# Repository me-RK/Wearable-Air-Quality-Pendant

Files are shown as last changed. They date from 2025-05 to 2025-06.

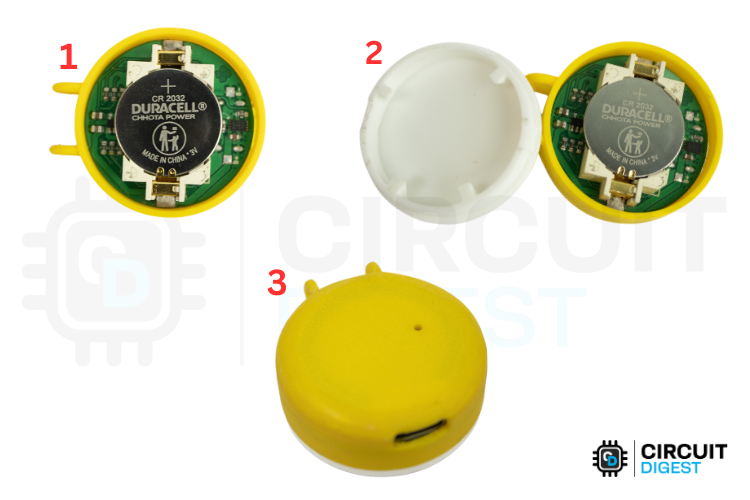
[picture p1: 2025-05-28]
Images/Assembled PCB and Enclosure.png

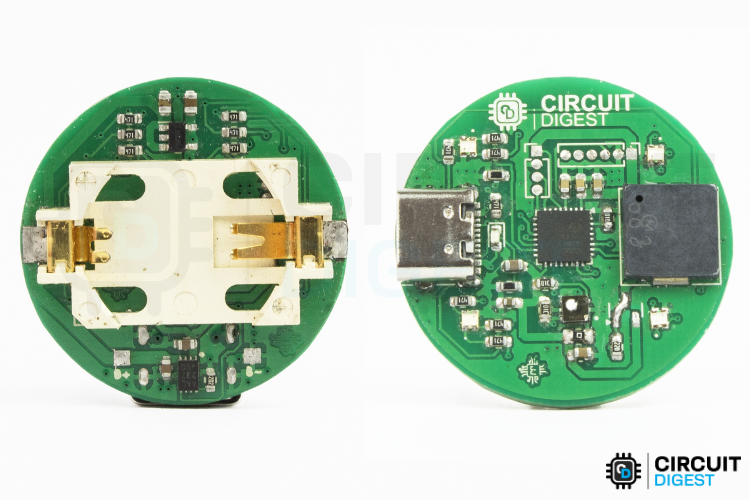
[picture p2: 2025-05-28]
Images/Assembled PCB front and Back.png

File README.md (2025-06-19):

Wearable Air Quality Pendant 🌬️
================================

A compact, battery-powered wearable device that continuously monitors air quality using TVOC detection. Get real-time feedback about your breathing environment through intuitive LED indicators and audio alerts.

Wearable Air Quality Pendant

Project Overview
-------------------

This DIY air quality monitor pendant uses professional-grade sensors to track Total Volatile Organic Compounds (TVOC) in real-time. Perfect for monitoring indoor air quality at home, office, or industrial environments.

### Key Features

-    **Real-time TVOC monitoring** using SGP40 sensor
-    **Ultra-low power design** with STM32U083KCU6 microcontroller
-    **Intuitive feedback** - Color-coded LEDs and musical alerts
-    **Wearable design** - Compact 32.5mm diameter pendant
-    **All-day battery life** with efficient power management
-    **Professional accuracy** with industrial-grade sensor

 Air Quality Classifications
------------------------------

| TVOC Level | Status | LED Color | Audio Alert |
| --- | --- | --- | --- |
| 0-200 | Good | 🟢 Green | Soft tone |
| 201-300 | Warning | 🟡 Yellow | Warning melody |
| 301-500 | Alarm | 🔴 Red | Urgent beeping |
| >500 | Error | 🔴 Flashing Red | Error tone |

 Hardware Components
-----------------------

### Main Components

-   **STM32U083KCU6** - Ultra-low-power microcontroller
-   **SGP40-D-R4** - Professional TVOC air quality sensor
-   **MCP73832T** - Li-Po battery charge controller
-   **ADPL44002** - Low-dropout voltage regulator
-   **EAST1616RGBA1** - RGB LEDs (4x)
-   **PKMCS0909E4000-R1** - Piezoelectric buzzer

### Power Management

-   Li-Po battery charging via USB-C
-   Regulated 2.5V supply for stable operation
-   Ultra-low power consumption for all-day use

📁 Repository Structure
-----------------------

```
├── Code/
│   └── Wearable_Air_Quality_Pendant/
│       ├── Wearable_Air_Quality_Pendant.ino
│       └── libraries/
├── PCB/
│   ├── Wearable-Air-Quality-Pendant.kicad_pro
│   ├── Schematic.pdf
│   └── Gerber_Files/
├── 3D_Models/
│   ├── Pendant_Top.stl
│   ├── Pendant_Bottom.stl
│   └── Assembly_Guide.pdf
├── Documentation/
│   ├── Circuit_Diagram.pdf
│   ├── Assembly_Instructions.pdf
│   └── BOM.csv
└── images/

```

🚀 Quick Start Guide
--------------------

### 1\. Hardware Assembly

1.  **Order PCB**: Use provided Gerber files
2.  **Solder components**: Follow the detailed BOM
3.  **3D print enclosure**: Use provided STL files
4.  **Assemble**: Insert PCB into printed enclosure

### 2\. Software Setup

1.  **Install Arduino IDE** (version 1.8.19 or newer)
2.  **Add STM32 board support**
3.  **Install required libraries**:
    -   DFRobot_SGP40
    -   PlayRtttl
    -   ptScheduler
4.  **Upload firmware** using ST-Link programmer

 Required Libraries
---------------------

Add these libraries through Arduino IDE Library Manager:

```
#include <DFRobot_SGP40.h>     // SGP40 sensor communication
#include <PlayRtttl.hpp>       // Musical tone generation
#include <ptScheduler.h>       // Non-blocking task scheduling

```

 Programming the Device
------------------------

### Hardware Requirements

-   **ST-Link V2 programmer** (required for STM32)
-   **USB-C cable** for power and charging
-   **3.3V power supply** during programming

### Upload Process

1.  Connect ST-Link to SWD pins (SWDIO, SWCLK)
2.  Select board: "STM32U0 series" in Arduino IDE
3.  Select programmer: "STM32CubeProgrammer (SWD)"
4.  Upload firmware

 PCB Specifications
---------------------

-   **Dimensions**: 32.5mm diameter
-   **Layers**: 2-layer PCB
-   **Thickness**: 1.6mm
-   **Components**: SMD (0603/0402 packages)
-   **Connector**: USB-C for charging

 3D Printing Guide
---------------------

### Print Settings

-   **Layer Height**: 0.2mm
-   **Infill**: 20%
-   **Supports**: Minimal (only for overhangs)
-   **Material**: PLA or PETG recommended

### Post-Processing

-   Light sanding for smooth finish
-   Ensure USB-C port alignment
-   Test fit before final assembly

Acknowledgments
------------------

-   **CircuitDigest** - Project development and documentation
-   **DFRobot** - SGP40 sensor library
-   **STMicroelectronics** - STM32 microcontroller support
-   **DigiKey** - Sponsors

Support
----------

-   **Detailed Tutorial**: [CircuitDigest Article](https://circuitdigest.com/videos/wearable-air-quality-pendant)
-   **Video Guide**: [YouTube Tutorial](https://youtube.com/watch?v=c5lP1kzYoBA)
-   **Issues**: Report bugs via GitHub Issues
-   **Discussion**: Join our community forum

Version History
-------------------

| Version | Date | Changes |
| --- | --- | --- |
| v1.0 | 2024-12 | Initial release |
| v1.1 | 2025-01 | Bug fixes, improved battery life |

* * * * *

**⭐ If this project helped you, please star the repository!**

**🔗 Related Projects:**

-   [Arduino Air Quality Monitor](https://github.com/Circuit-Digest/Arduino-Air-Quality-Monitor)
-   [IoT Air Quality System](https://github.com/Circuit-Digest/IoT-Air-Quality-System)

**📧 Contact:** support@circuitdigest.com

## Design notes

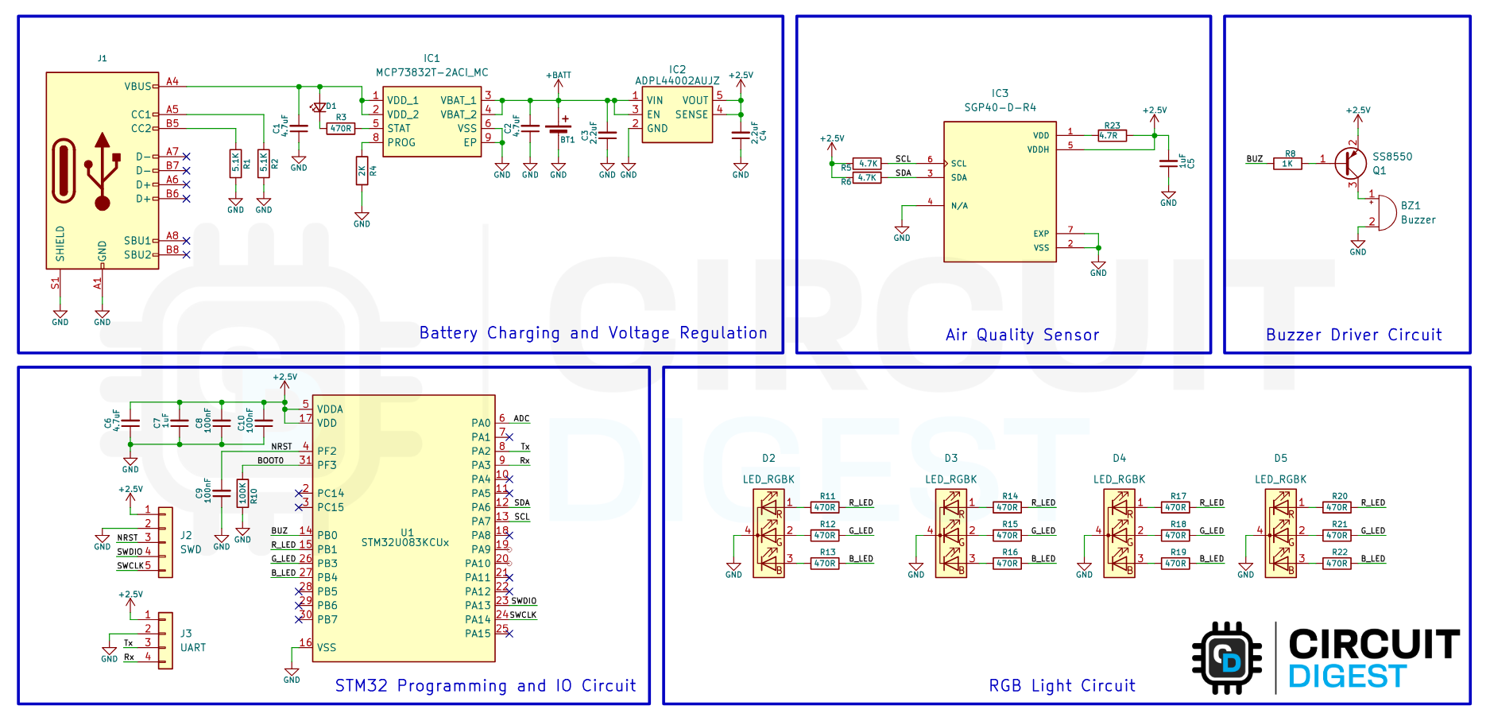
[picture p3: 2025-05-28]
Images/Schematic.png

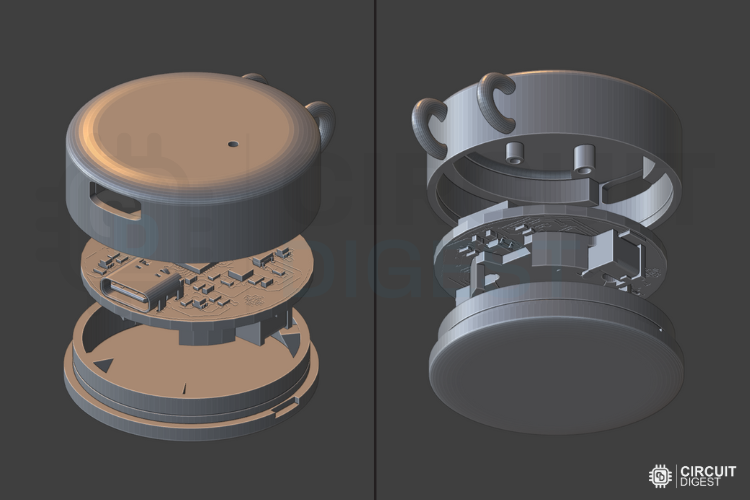
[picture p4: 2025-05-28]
Images/3D Enclosure DEsign.png

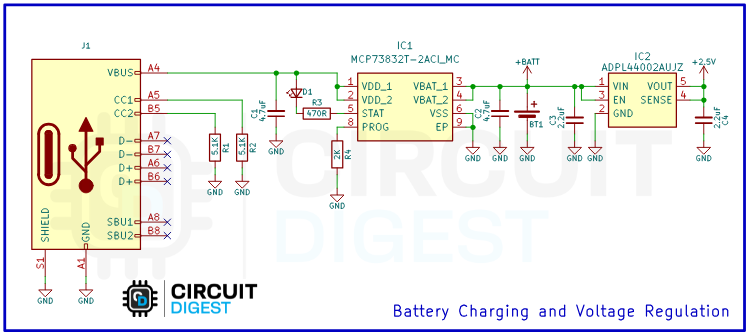
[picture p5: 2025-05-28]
Images/Battery Charging and Voltage Regulation.png

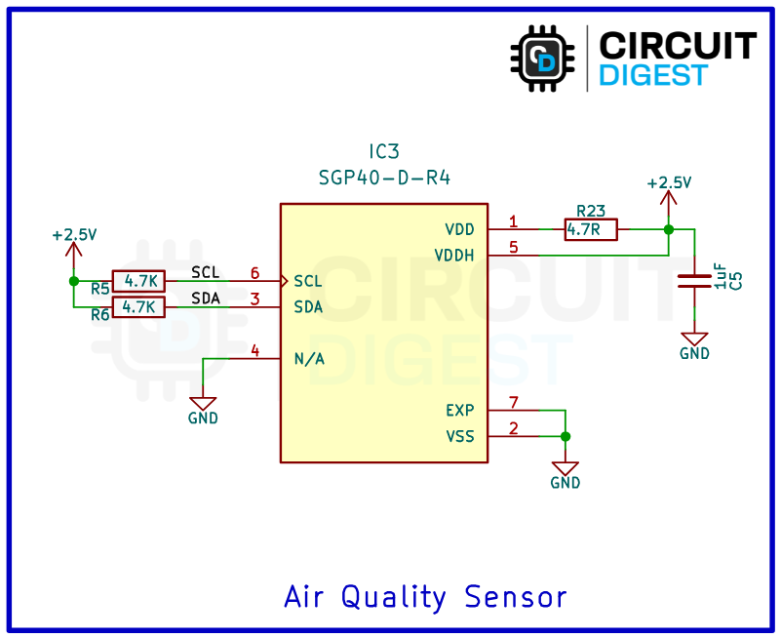
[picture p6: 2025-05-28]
Images/Air Quality Sensor.png

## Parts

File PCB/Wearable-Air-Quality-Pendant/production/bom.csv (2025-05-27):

Designator | Footprint | Quantity | Value | LCSC Part #
_2, |  | 2
BT1 | BAT_1060 | 1 | Battery_Cell
BZ1 | PKMCS0909E4000-R1_MUR | 1 | Buzzer
C1, C2, C6 | 0603 | 3 | 4.7uF
C10, C8, C9 | 0603 | 3 | 100nF
C3, C4 | 0603 | 2 | 2.2uF
C5, C7 | 0603 | 2 | 1uF
D1 | 0603 | 1 | LED_Small
D2, D3, D4, D5 | EAST1616RGBA1 | 4 | LED_RGBK
IC1 | SON50P300X200X100-9N-D | 1 | MCP73832T-2ACI_MC
IC2 | SOT95P280X100-5N | 1 | ADPL44002AUJZ
IC3 | XCDR_SGP40-D-R4 | 1 | SGP40-D-R4
J1 | USB_C_Receptacle_Palconn_UTC16-G | 1 | USB_C_Receptacle_USB2.0_16P
J2 | PinHeader_1x06_P1.27mm_Vertical | 1 | SWD
J3 | PinHeader_1x04_P1.27mm_Vertical | 1 | UART
Q1 | SOT-23 | 1 | SS8550
R1, R2 | 0603 | 2 | 5.1K
R10 | 0603 | 1 | 100K
R11, R12, R13, R14, R15, R16, R17, R18, R19, R20, R21, R22, R3 | 0603 | 13 | 470R
R23 | 0805 | 1 | 4.7R
R4 | 0603 | 1 | 2K
R5, R6 | 0603 | 2 | 4.7K
R8 | 0603 | 1 | 1K
U1 | QFN-32-1EP_5x5mm_P0.5mm_EP3.45x3.45mm | 1 | STM32U083KCUx

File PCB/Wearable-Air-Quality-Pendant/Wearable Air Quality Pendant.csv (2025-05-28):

Reference | Qty | Value | Datasheet | Manufacturer_Name | Manufacturer_Part_Number
BT1 | 1 | Battery_Cell | ~
BZ1 | 1 | Buzzer | ~
C1,C2,C6 | 3 | 4.7uF | ~
C3,C4 | 2 | 2.2uF | ~
C5,C7 | 2 | 1uF | ~
C8,C9,C10 | 3 | 100nF | ~
D1 | 1 | LED_Small | ~
D2,D3,D4,D5 | 4 | LED_RGBK | ~
IC1 | 1 | MCP73832T-2ACI_MC | http://ww1.microchip.com/downloads/en/DeviceDoc/20001984g.pdf | Microchip | MCP73832T-2ACI/MC
IC2 | 1 | ADPL44002AUJZ | https://www.analog.com/ADPL44002/datasheet | Analog Devices | ADPL44002AUJZ2.5-R7
IC3 | 1 | SGP40-D-R4
J1 | 1 | USB_C_Receptacle_USB2.0_16P | https://www.usb.org/sites/default/files/documents/usb_type-c.zip
J2 | 1 | SWD | ~
J3 | 1 | UART | ~
Q1 | 1 | SS8550 | http://www.secosgmbh.com/datasheet/products/SSMPTransistor/SOT-23/SS8550.pdf
R1,R2 | 2 | 5.1K | ~
R3,R11,R12,R13,R14,R15,R16,R17,R18,R19,R20,R21,R22 | 13 | 470R | ~
R4 | 1 | 2K | ~
R5,R6 | 2 | 4.7K | ~
R8 | 1 | 1K | ~
R10 | 1 | 100K | ~
R23 | 1 | 4.7R | ~
U1 | 1 | STM32U083KCUx | https://www.st.com/resource/en/datasheet/stm32u083kc.pdf

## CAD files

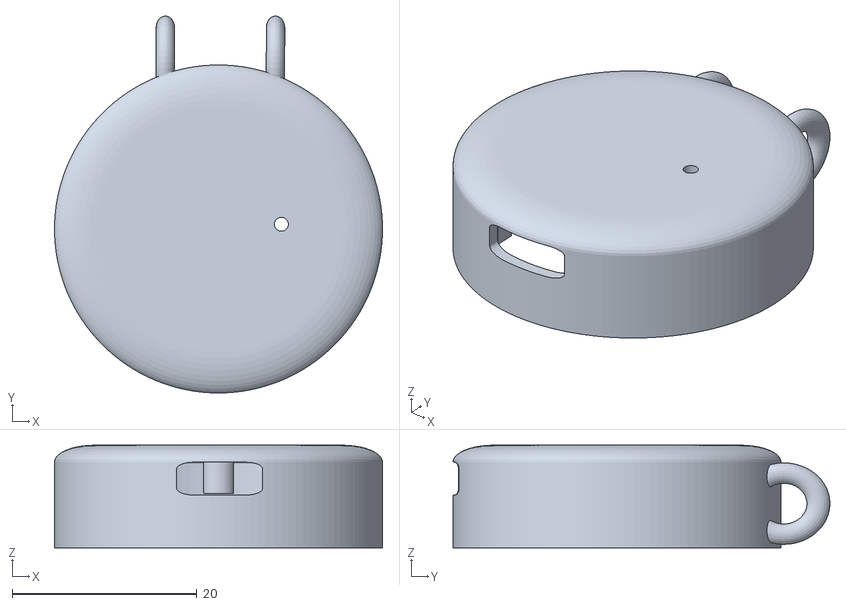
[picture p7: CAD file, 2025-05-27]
Enclosure STL Files/Wearable_Air_Quality_Pendant_Top.stl
35.5 x 40.8 x 11.1

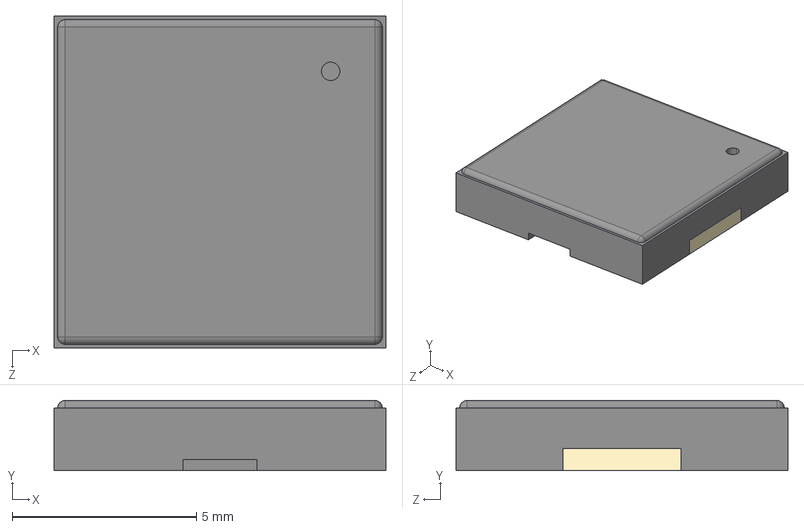
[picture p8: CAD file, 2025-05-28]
PCB/Wearable-Air-Quality-Pendant/3d Models/PKMCS0909E4000-R1.STEP
9.00 x 1.90 x 9.00 mm

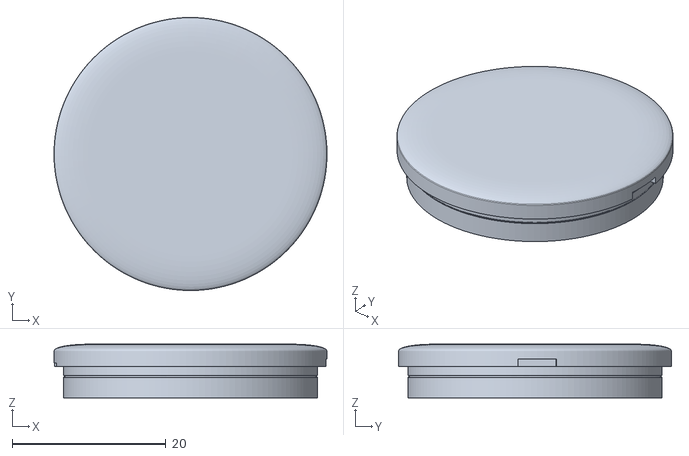
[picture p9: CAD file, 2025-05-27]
Enclosure STL Files/Wearable_Air_Quality_Pendant_Bottom.stl
35.5 x 35.5 x 6.97

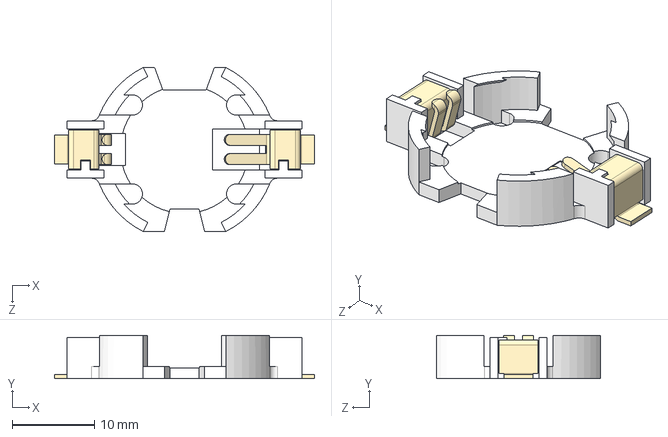
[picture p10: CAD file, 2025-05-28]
PCB/Wearable-Air-Quality-Pendant/3d Models/BU2032SM-JJ-GTR.STEP
31.7 x 5.30 x 20.0 mm

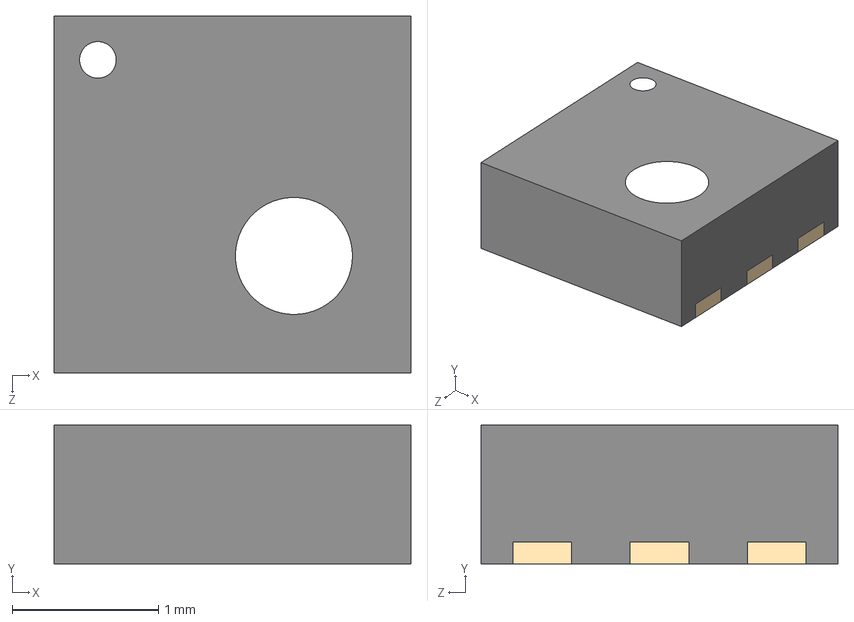
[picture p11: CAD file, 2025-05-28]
PCB/Wearable-Air-Quality-Pendant/3d Models/SGP40-D-R4.STEP
2.44 x 0.95 x 2.44 mm

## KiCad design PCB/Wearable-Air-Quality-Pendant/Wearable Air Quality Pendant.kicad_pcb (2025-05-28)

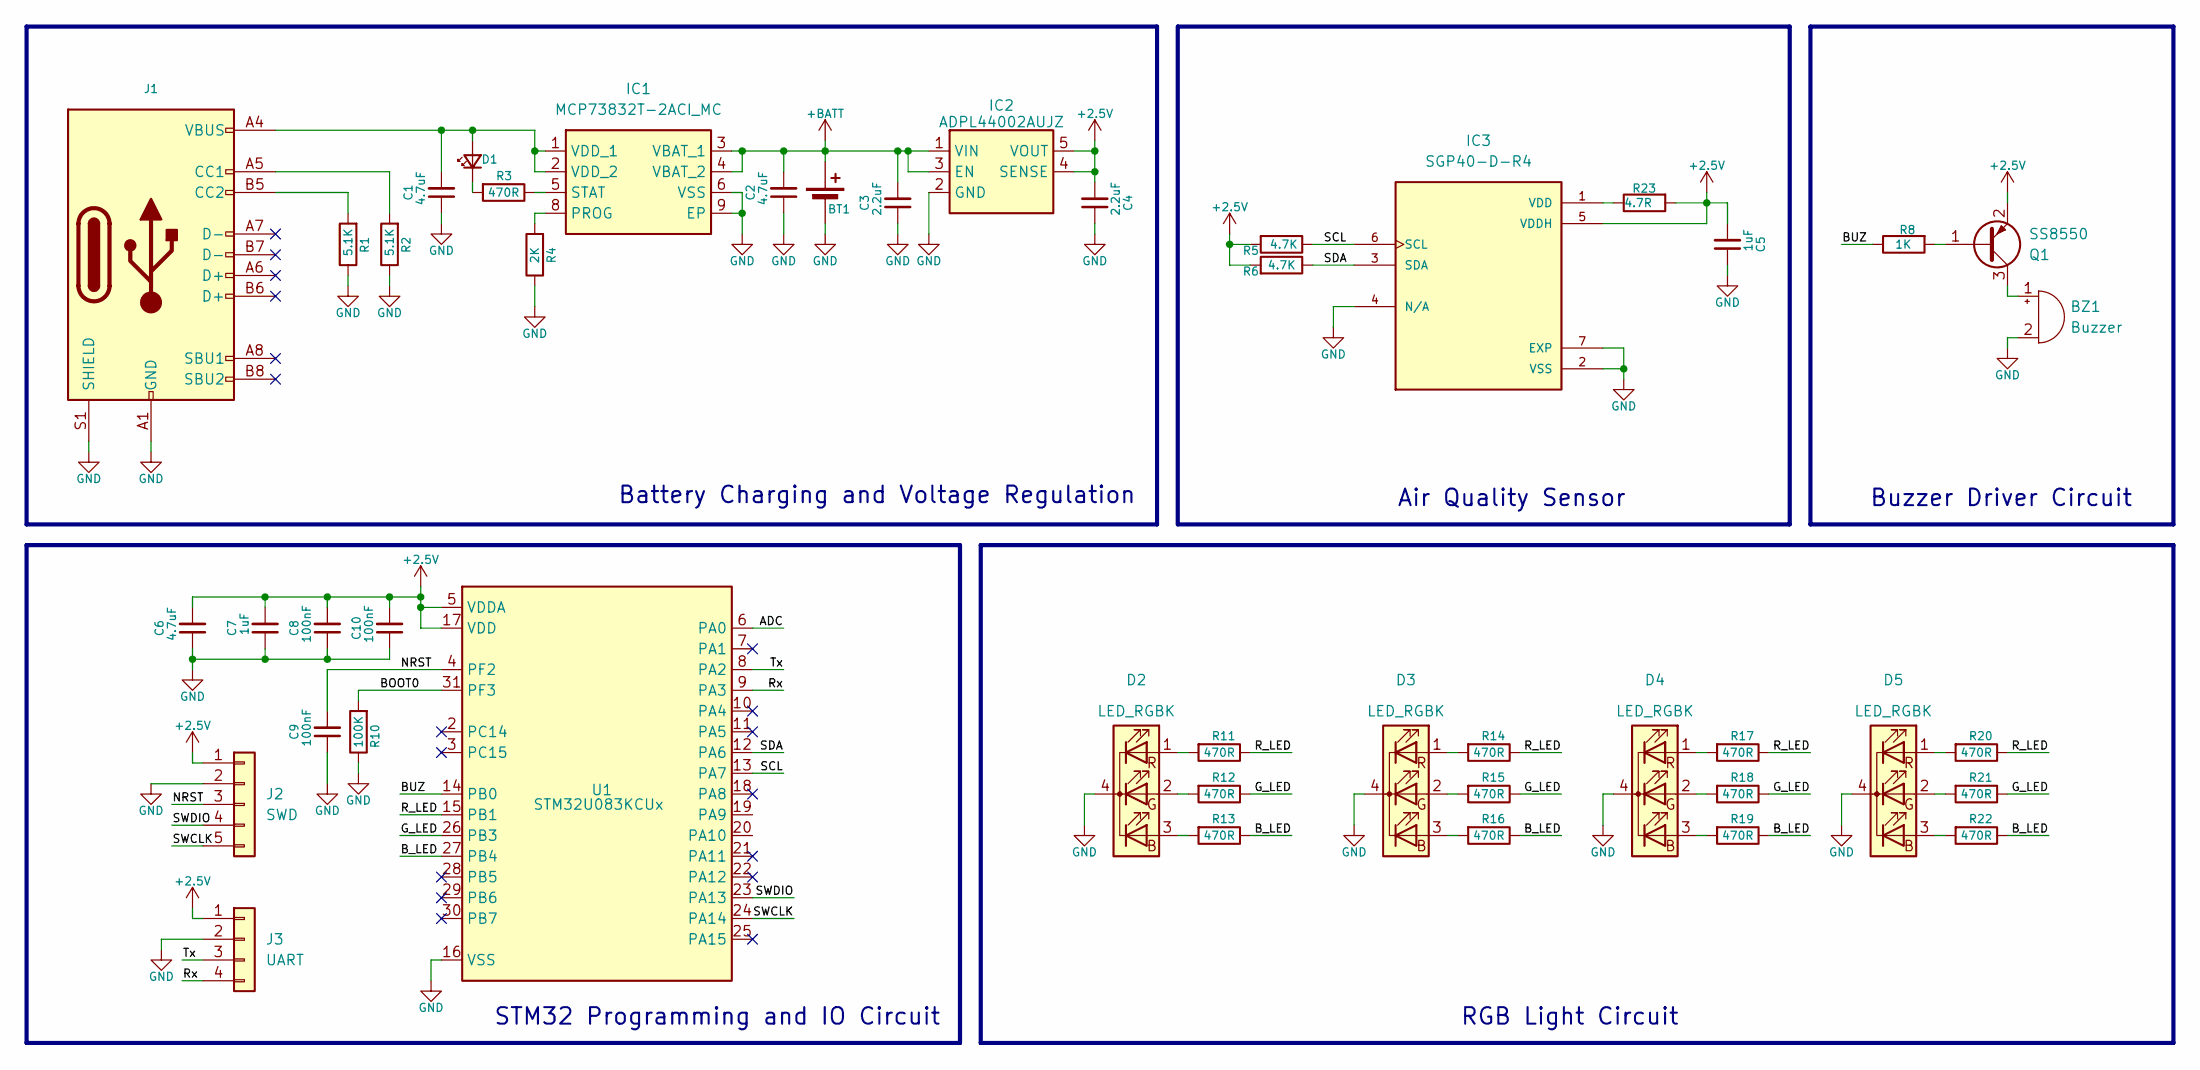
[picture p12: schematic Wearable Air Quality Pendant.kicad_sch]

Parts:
BT1: Battery_Cell; BAT_1060
BZ1: Buzzer; PKMCS0909E4000-R1_MUR
C1, C2, C6: 4.7uF; C_0603_1608Metric
C3, C4: 2.2uF; C_0603_1608Metric
C5, C7: 1uF; C_0603_1608Metric
C8, C9, C10: 100nF; C_0603_1608Metric
D1: LED_Small; LED_0603_1608Metric
D2, D3, D4, D5: LED_RGBK; EAST1616RGBA1
IC1: MCP73832T-2ACI_MC; SON50P300X200X100-9N-D; Mouser Part Number 579-MCP73832T-2ACIMC
IC2: ADPL44002AUJZ; SOT95P280X100-5N; Manufacturer_Part_Number ADPL44002AUJZ2.5-R7
IC3: SGP40-D-R4; XCDR_SGP40-D-R4; PARTREV 1.2
J1: USB_C_Receptacle_USB2.0_16P; USB_C_Receptacle_Palconn_UTC16-G
J2: SWD; PinHeader_1x06_P1.27mm_Vertical
J3: UART; PinHeader_1x04_P1.27mm_Vertical
Q1: SS8550; SOT-23
R1, R2: 5.1K; R_0603_1608Metric
R3, R11, R12, R13, R14, R15, R16, R17, R18, R19, R20, R21, R22: 470R; R_0603_1608Metric
R4: 2K; R_0603_1608Metric
R5, R6: 4.7K; R_0603_1608Metric
R8: 1K; R_0603_1608Metric
R10: 100K; R_0603_1608Metric
R23: 4.7R; R_0805_2012Metric
U1: STM32U083KCUx; QFN-32-1EP_5x5mm_P0.5mm_EP3.45x3.45mm

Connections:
+2.5V: C4.2, C5.2, C6.2, C7.2, C8.2, C10.2, IC2.4 (SENSE), IC2.5 (VOUT), IC3.5 (VDDH), J2.1, J3.1, Q1.2 (E), R5.2, R6.2, R23.2, U1.1 (VDD), U1.5 (VDDA), U1.17 (VDD)
+BATT: BT1.P (+), C2.2, C3.2, IC1.3 (VBAT_1), IC1.4 (VBAT_2), IC2.1 (VIN), IC2.3 (EN)
/ADC: U1.6 (PA0)
/BOOT0: R10.2, U1.31 (PF3)
/BUZ: R8.1, U1.14 (PB0)
/B_LED: R13.1, R16.1, R19.1, R22.1, U1.27 (PB4)
/G_LED: R12.1, R15.1, R18.1, R21.1, U1.26 (PB3)
/NRST: C9.2, J2.3, U1.4 (PF2)
/R_LED: R11.1, R14.1, R17.1, R20.1, U1.15 (PB1)
/Rx: J3.4, U1.9 (PA3)
/SCL: IC3.6 (SCL), R5.1, U1.13 (PA7)
/SDA: IC3.3 (SDA), R6.1, U1.12 (PA6)
/SWCLK: J2.5, U1.24 (PA14)
/SWDIO: J2.4, U1.23 (PA13)
/Tx: J3.3, U1.8 (PA2)
GND: BT1.N (-), BZ1.2 (-), C1.1, C2.1, C3.1, C4.1, C5.1, C6.1, C7.1, C8.1, C9.1, C10.1, D2.4 (K), D3.4 (K), D4.4 (K), D5.4 (K), IC1.6 (VSS), IC1.9 (EP), IC2.2 (GND), IC3.2 (VSS), IC3.4 (N/A), IC3.7 (EXP), J1.A1 (GND), J1.A12 (GND), J1.B1 (GND), J1.B12 (GND), J1.S1 (SHIELD), J2.2, J3.2, R1.1, R2.1, R4.1, R10.1, U1.16 (VSS), U1.32 (VSS), U1.33 (VSS)
unnamed: BZ1.1 (+), Q1.3 (C)
unnamed: C1.2, D1.2 (A), IC1.1 (VDD_1), IC1.2 (VDD_2), J1.A4 (VBUS), J1.A9 (VBUS), J1.B4 (VBUS), J1.B9 (VBUS)
unnamed: D1.1 (K), R3.2
unnamed: D2.3 (BA), R13.2
unnamed: D2.2 (GA), R12.2
unnamed: D2.1 (RA), R11.2
unnamed: D3.3 (BA), R16.2
unnamed: D3.2 (GA), R15.2
unnamed: D3.1 (RA), R14.2
unnamed: D4.3 (BA), R19.2
unnamed: D4.2 (GA), R18.2
unnamed: D4.1 (RA), R17.2
unnamed: D5.3 (BA), R22.2
unnamed: D5.2 (GA), R21.2
unnamed: D5.1 (RA), R20.2
unnamed: IC1.8 (PROG), R4.2
unnamed: IC1.5 (STAT), R3.1
unnamed: IC3.1 (VDD), R23.1
unnamed: J1.A5 (CC1), R2.2
unnamed: J1.B5 (CC2), R1.2
unnamed: Q1.1 (B), R8.2

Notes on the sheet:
Air Quality Sensor
STM32 Programming and IO Circuit
Battery Charging and Voltage Regulation
RGB Light Circuit
Buzzer Driver Circuit

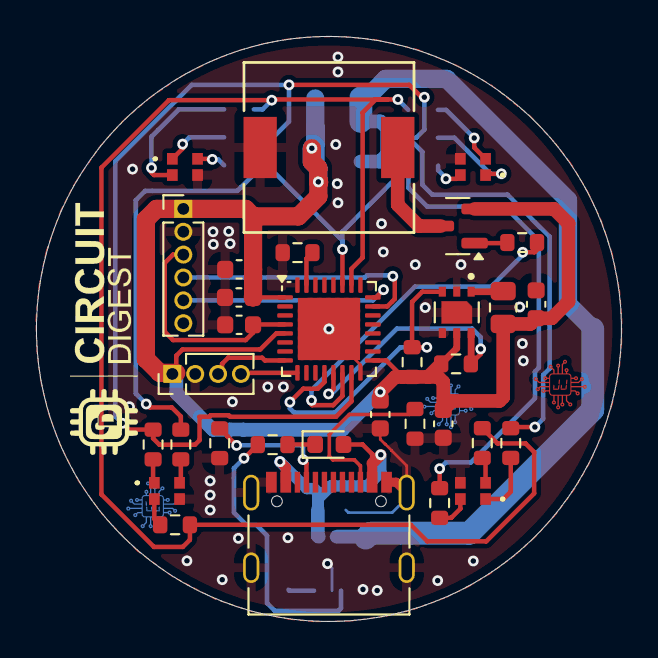
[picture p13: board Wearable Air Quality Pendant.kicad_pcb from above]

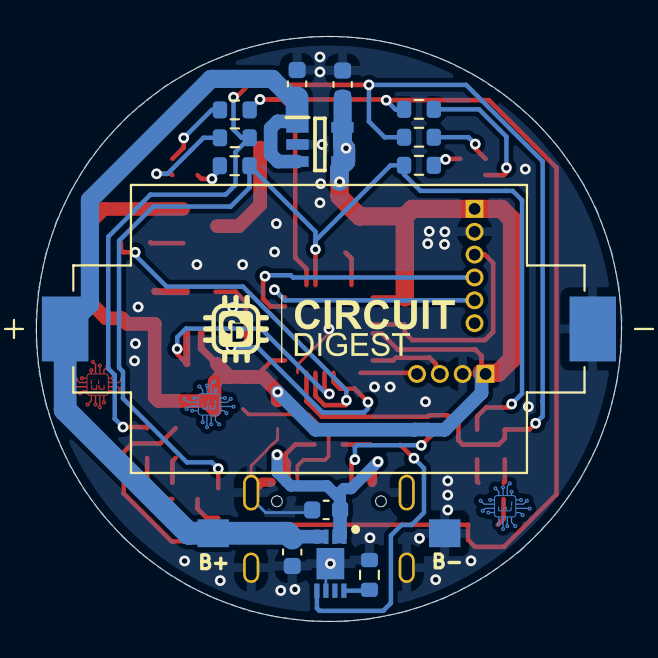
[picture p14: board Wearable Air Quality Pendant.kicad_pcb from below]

Board: 2 copper layers, 32.5 x 32.5 mm, 46 parts (14 on the bottom side), 36 nets.

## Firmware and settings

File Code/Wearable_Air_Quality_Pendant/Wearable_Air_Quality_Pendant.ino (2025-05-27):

/*
  =======================================================================
  Project: Air Quality Monitor with TVOC Index using SGP40 Sensor

  Features:
  - Reads Total Volatile Organic Compounds (TVOC) index from SGP40 sensor
  - Indicates air quality using LEDs (Red, Green) with smooth fading effect
  - Plays RTTTL tone alerts for different air quality levels via buzzer
  - Displays TVOC values via LPUART serial (PA2, PA3)
  - Shows error states with visual (LED) and audible (buzzer) indication

  Working:
  - SGP40 sensor periodically reads TVOC index
  - Based on the index value, system classifies air as:
      0–200   → Good (Soft tone, Green LED)
      201–300 → Warning (Warn tone, Yellow LED)
      301–500 → Alarm (Alarm tone, Red LED)
  - If TVOC exceeds 500 or sensor fails, Error tone & Red LED flash
  - Scheduler ensures non-blocking periodic sensor read, LED updates, and sound
  =======================================================================
*/

#include <DFRobot_SGP40.h> // need to install
#include <HardwareSerial.h>
#include <Arduino.h>
#include <PlayRtttl.hpp> // need to install
#include <ptScheduler.h> // need to install

// LED and Buzzer pin definitions
#define RED_PIN PB3
#define GREEN_PIN PB4
#define BUZZER_PIN PB0

// Define serial on PA3 (RX) and PA2 (TX)
HardwareSerial MyLPUART1(PA3, PA2);

// Create SGP40 sensor object
DFRobot_SGP40 mySgp40;

// Variables for tone request and fading effect
int tvoc = 0;
int toneRequest = -1;
int fadeStep = 0;

// Time tracking variables for non-blocking operations
unsigned long prevLedTime = 0;
unsigned long prevToneTime = 0;

// Define RTTTL tone melodies
const char softTone[] = "Soft:d=8,o=5,b=100:g";
const char warnTone[] = "Warn:d=4,o=5,b=120:c,e,g";
const char alarmTone[] = "Alarm:d=16,o=5,b=180:c6,c6,c6";
const char startTone[] = "Start:d=8,o=6,b=120:c,e,g";
const char errorTone[] = "Error:d=4,o=5,b=160:c,c,r,c";

// Enum to associate tone types with time intervals
enum ToneType {
  TONE_SOFT = 5000,
  TONE_WARN = 2000,
  TONE_ALARM = 500,
  TONE_START = 1000,
  TONE_ERROR = 200
};

// Task scheduler for non-blocking periodic functions
ptScheduler readSensorTask(PT_TIME_1S);   // Sensor reading every 1 second
ptScheduler lightTask(PT_TIME_100MS);     // LED update task
ptScheduler soundTask(PT_TIME_100MS);     // Buzzer task

// Function declarations
void playTone(ToneType tone);
void updateLedFade(ToneType tone);
void showErrorState();
void readAndEvaluateAir();

void setup() {
  MyLPUART1.begin(115200);

  // Initialize output pins
  pinMode(RED_PIN, OUTPUT);
  pinMode(GREEN_PIN, OUTPUT);
  pinMode(BUZZER_PIN, OUTPUT);

  MyLPUART1.println("sgp40 is starting, the reading can be taken after 10 seconds...");

  // Startup indication
  updateLedFade(TONE_START);
  playTone(TONE_START);

  // Initialize sensor
  if (!mySgp40.begin(10000)) {
    MyLPUART1.println("Failed to init chip. Please check connection.");
    showErrorState();
    while (true);  // Stop execution on failure
  }

  MyLPUART1.println("sgp40 initialized successfully!");
}

void loop() {
  // Periodically read sensor
  if (readSensorTask.call()) {
    readAndEvaluateAir();
  }

  // Update LED fading effect based on tone
  if (lightTask.call() && toneRequest != -1) {
    updateLedFade((ToneType)toneRequest);
  }

  // Play tone based on tone request
  if (soundTask.call() && toneRequest != -1 && toneRequest != TONE_SOFT) {
    playTone((ToneType)toneRequest);
  }
}

// Reads TVOC value and determines air quality level
void readAndEvaluateAir() {
  tvoc = mySgp40.getVoclndex();

  MyLPUART1.print("vocIndex = ");
  MyLPUART1.println(tvoc);

  if (tvoc <= 200) {
    toneRequest = TONE_SOFT;
  } else if (tvoc <= 300) {
    toneRequest = TONE_WARN;
  } else if (tvoc <= 500) {
    toneRequest = TONE_ALARM;
  } else {
    MyLPUART1.println("Invalid TVOC value.");
    showErrorState();
  }
}

// Smooth LED fading based on tone type
void updateLedFade(ToneType tone) {
  static const int maxBrightness = 255;
  static const int fadeSpeed = 5;
  static const int fadeDelay = 10;

  unsigned long currentMillis = millis();
  if (currentMillis - prevToneTime < tone) return;
  prevToneTime = currentMillis;

  int redTarget = 0, greenTarget = 0;

  // Set target brightness levels based on tone
  switch (tone) {
    case TONE_SOFT: greenTarget = maxBrightness; break;                  // Green only
    case TONE_WARN: redTarget = greenTarget = maxBrightness; break;     // Yellow (Red + Green)
    case TONE_ALARM:
    case TONE_ERROR: redTarget = maxBrightness; break;                  // Red only
    default: break;
  }

  // Fade in
  for (int brightness = 0; brightness <= 255; brightness += fadeSpeed) {
    analogWrite(RED_PIN, (brightness * redTarget) / 255);
    analogWrite(GREEN_PIN, (brightness * greenTarget) / 255);
    delay(fadeDelay);
  }

  // Fade out
  for (int brightness = 255; brightness >= 0; brightness -= fadeSpeed) {
    analogWrite(RED_PIN, (brightness * redTarget) / 255);
    analogWrite(GREEN_PIN, (brightness * greenTarget) / 255);
    delay(fadeDelay);
  }

  // Reset if loop exceeds max fade cycle
  fadeStep += fadeSpeed;
  if (fadeStep > 510) {
    analogWrite(RED_PIN, 0);
    analogWrite(GREEN_PIN, 0);
  }
}

// Play a tone melody corresponding to the tone type
void playTone(ToneType tone) {
  unsigned long currentMillis = millis();
  if (currentMillis - prevLedTime < tone) return;
  prevLedTime = currentMillis;

  switch (tone) {
    case TONE_SOFT:  playRtttlBlockingPGM(BUZZER_PIN, softTone); break;
    case TONE_WARN:  playRtttlBlockingPGM(BUZZER_PIN, warnTone); break;
    case TONE_ALARM: playRtttlBlockingPGM(BUZZER_PIN, alarmTone); break;
    case TONE_START: playRtttlBlockingPGM(BUZZER_PIN, startTone); break;
    case TONE_ERROR: playRtttlBlockingPGM(BUZZER_PIN, errorTone); break;
  }
}

// Show error condition using LED and buzzer
void showErrorState() {
  toneRequest = TONE_ERROR;
  soundTask.enable();
}
